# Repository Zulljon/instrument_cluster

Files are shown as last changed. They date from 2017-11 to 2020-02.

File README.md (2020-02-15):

View this project on [CADLAB.io](https://cadlab.io/project/2495). 

# ECU emulator v3.1a
PCB part of project (source codes unavailable!)

## Scheme
in development...
in development...
in development...
in development...

## PCB
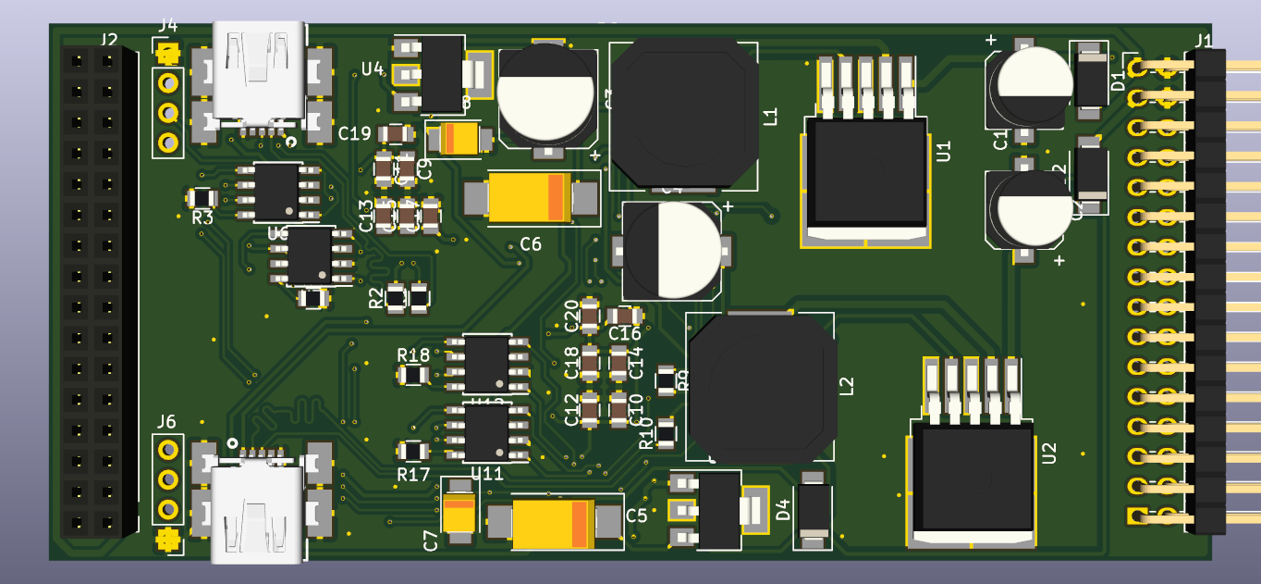
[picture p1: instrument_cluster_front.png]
front side in development...

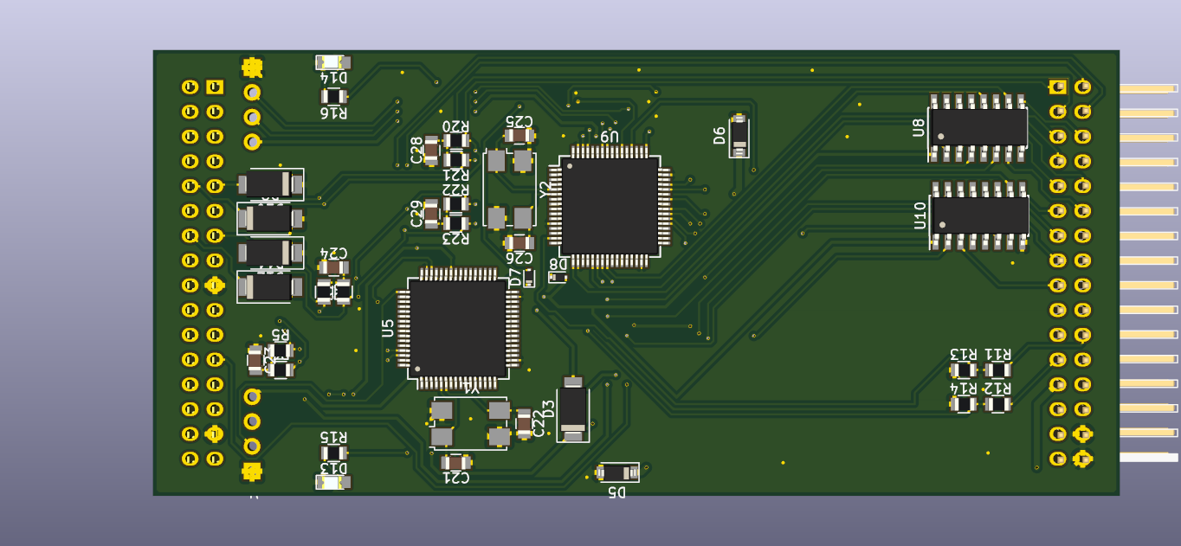
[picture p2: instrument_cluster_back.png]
back side in development...

### With FreeCAD PCB mod
in development...
### With FreeCAD KiCAD StepUp mod
in development...

## Tools
- KiCAD v4.0.7
- FreeCAD v0.15

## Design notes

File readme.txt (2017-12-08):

Name of each file consists from name of project and it`s purpose, for example:
	Rover_Commander_v3.1a-B.Cu.gbr
		Rover_Commander_v3.1a - project name
		-B.Cu.gbr - нижний слой меди

соответственно:
	
	*-B.Cu.gbr  	-	back copper layer
	*-B.Fab.gbr 	-	footprint assemly on board`s back 
	*-B.Mask.gbr	-	solder mask on board`s back
	*-B.Paste.gbr	-	solder paste on board`s back
	*-B.SilkS.gbr	-	silkscreen on board`s back
	*-B.CrtYd.gbr	-	footprints courtyards on board`s back
	*-B.Adhes.gbr	-	adhesive on board`s back

	*-F.Cu.gbr  	-	front copper layer
	*-F.Fab.gbr 	-	footprint assemly on board`s front
	*-F.Mask.gbr	-	solder mask on board`s front
	*-F.Paste.gbr	-	solder paste on board`s front
	*-F.SilkS.gbr	-	silkscreen on board`s front
	*-F.CrtYd.gbr	-	footprints courtyards on board`s front
	*-F.Adhes.gbr	-	adhesive on board`s front

	*-Edge.Cuts.gbr	-	board`s perimeter definition
	*.drl			-	excellon drill file
	*-drl_map.gbr	-	map drill file

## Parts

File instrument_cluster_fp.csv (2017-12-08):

Source: | z:/KiCAD/instrument_cluster/instrument_cluster.sch
Date: | 08.12.2017 12:24:34
Tool: | Eeschema 4.0.7
Generator: | C:/Program Files/KiCad/bin/scripting/plugins/bom_csv_grouped_by_value_with_fp.py
Component Count: | 86
Ref | Qnty | Value | Cmp name | Footprint | Description | Vendor
C1, C2, | 2 | 100uF x 30V | CP | Capacitors_SMD:CP_Elec_6.3x7.7 | Polarised capacitor
C3, C4, | 2 | 330uF x 10V | CP | Capacitors_SMD:CP_Elec_8x10 | Polarised capacitor
C5, C6, | 2 | 100uF x 10V | CP | Capacitors_Tantalum_SMD:CP_Tantalum_Case-D_EIA-7343-31_Hand | Polarised capacitor
C7, C8, | 2 | 10uF x 10V | CP | Capacitors_Tantalum_SMD:CP_Tantalum_Case-B_EIA-3528-21_Wave | Polarised capacitor
C9, C11, C13, C15, C17, C10, C12, C14, C16, C18, | 10 | 100nF | C | Capacitors_SMD:C_0805 | Unpolarized capacitor
C19, C20, | 2 | 4.7uF | C | Capacitors_SMD:C_0805 | Unpolarized capacitor
C22, C21, C26, C25, | 4 | 16pF | C | Capacitors_SMD:C_0805 | Unpolarized capacitor
C23, C24, C28, C29, | 4 | 10pF | C | Capacitors_SMD:C_0805 | Unpolarized capacitor
D1, D3, D4, D2, | 4 | SS22A-SS210A-galaxy | D_Schottky | Diodes_SMD:D_SMA | Schottky diode
D5, D6, | 2 | 1N5819 | D_Schottky | Diodes_SMD:D_SOD-123 | Schottky diode
D7, D8, | 2 | PMLL4148L.115 | D | Diodes_SMD:D_SC-80 | Diode
D10, D9, D11, D12, | 4 | SMAJ33CA-TR | D_TVS | Diodes_SMD:D_SMA | Bidirectional transient-voltage-suppression (TVS) diode
D13, D14, | 2 | LED | LED | LEDs:LED_0805 | LED generic
J1, | 1 | Conn_02x16_Top_Bottom | Conn_02x16_Top_Bottom | zulljon:Pin_Header_Angled_2x16_Pitch2.54mm | Generic connector, double row, 02x16, top/bottom pin numbering scheme (row 1: 1...pins_per_row, row2: pins_per_row+1 ... num_pins)
J2, | 1 | Conn_02x16_Top_Bottom | Conn_02x16_Top_Bottom | zulljon:Socket_Strip_Straight_2x16_Pitch2.54mm | Generic connector, double row, 02x16, top/bottom pin numbering scheme (row 1: 1...pins_per_row, row2: pins_per_row+1 ... num_pins)
J3, | 1 | USB mini-B SMD | 54819-0572 | zpkl:USB_mini_B | Surface mount onthego connector,1A 30V Molex On-The-Go Series Right Angle SMT Version 2.0 Type B Mini USB Connector Receptacle, 30 V, 1A
J4, J6, | 2 | NOT_FITTED_SWD_Conn_01x04_Male | Conn_01x04_Male | Pin_Headers:Pin_Header_Straight_1x04_Pitch2.54mm | Generic connector, single row, 01x04
J5, | 1 | 54819-0572 | 54819-0572 | zpkl:USB_mini_B | Surface mount onthego connector,1A 30V Molex On-The-Go Series Right Angle SMT Version 2.0 Type B Mini USB Connector Receptacle, 30 V, 1A
L1, L2, | 2 | 330uH | L | Inductors_SMD:L_12x12mm_h8mm | Inductor
R2, R1, R10, R9, | 4 | 22 | R | Resistors_SMD:R_0805 | Resistor
R3, R4, R17, R18, R16, | 5 | 10k | R | Resistors_SMD:R_0805 | Resistor
R6, R5, R8, R7, R21, R20, R23, R22, | 8 | 60 | R | Resistors_SMD:R_0805 | Resistor
R11, R12, | 2 | 9k | R | Resistors_SMD:R_0805 | Resistor
R13, R14, | 2 | 2.2k | R | Resistors_SMD:R_0805 | Resistor
R15, | 1 | 1k | R | Resistors_SMD:R_0805 | Resistor
U1, U2, | 2 | LM2575S-5.0_NOPB | LM2575S-5.0_NOPB | TO_SOT_Packages_SMD:TO-263-5_TabPin6 | SIMPLE SWITCHER 4.5V to 40V, 1A Low Component Count Step-Down Regulator
U3, U4, | 2 | LD1117S33TR_SOT223 | LD1117S33TR_SOT223 | TO_SOT_Packages_SMD:SOT-223-3_TabPin2 | 1A Low Dropout regulator, positive, 1.5V fixed output, SOT-223
U5, U9, | 2 | STM32F105RBTx | STM32F105RBTx-RESCUE-instrument_cluster | Housings_QFP:LQFP-64_10x10mm_Pitch0.5mm
U6, U7, U11, U12, | 4 | TJA1040T | TJA1040T | Housings_SOIC:SOIC-8_3.9x4.9mm_Pitch1.27mm | TJA1040T, High-Speed CAN Transceiver, standby mode, split pin, SOIC-8
U10, U8, | 2 | 74HC4050D | 74HC4050D | Housings_SOIC:SOIC-16_3.9x9.9mm_Pitch1.27mm | 74HC4050D, 6-Bit Buffer, Converter, HC, Non-Inverting 2 to 6V 16-Pin SOIC
Y1, Y2, | 2 | Crystal KX-13 25MHz | Crystal_GND24 | Crystals:Crystal_SMD_7050-4pin_7.0x5.0mm | Four pin crystal (GND on pins 2 and 4), e.g. in SMD package

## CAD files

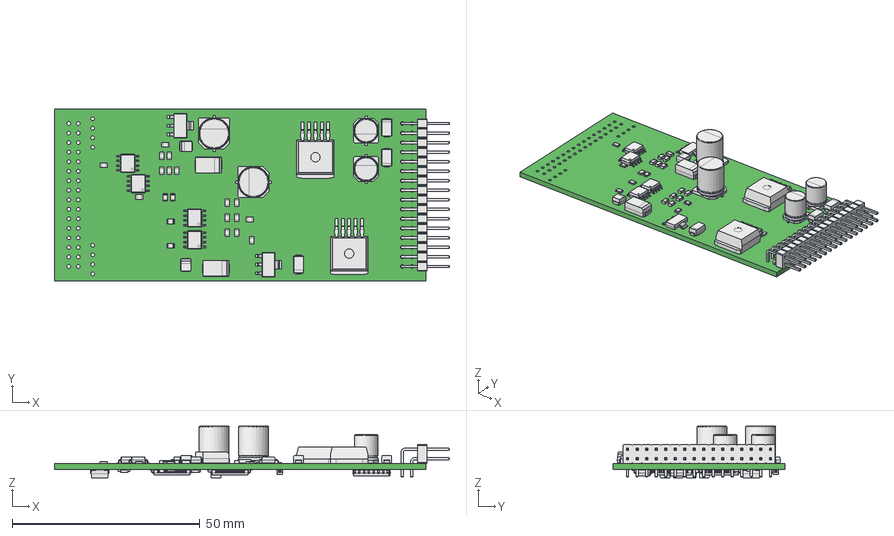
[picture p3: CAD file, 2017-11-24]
instrument_cluster.FCStd
105.3 x 45.7 x 13.8 mm
Pcb
CP_Elec_6.3x7.7_
CP_Elec_6.3x7.7_001
CP_Elec_8x1.0_
CP_Elec_8x1.0_001
CP_Tantalum_Case-D_EIA-7343-31_
CP_Tantalum_Case-D_EIA-7343-31_001
CP_Tantalum_Case-B_EIA-3528-21_
CP_Tantalum_Case-B_EIA-3528-21_001
C_0805_
C_0805_001
C_0805_002
C_0805_003
C_0805_004
C_0805_005
C_0805_006
C_0805_007
C_0805_008
C_0805_009
C_0805_010
C_0805_011
C_0805_012
C_0805_013
C_0805_014
C_0805_015
C_0805_016
C_0805_017
C_0805_018
C_0805_019
D_SMA_
D_SMA_001
D_SMA_002
D_SMA_003
D_SOD_123_
D_SOD_123_001
D_SC_80_
D_SC_80_001
R_0805_
R_0805_001
R_0805_002
R_0805_003
R_0805_004
R_0805_005
R_0805_006
R_0805_007
R_0805_008
R_0805_009
R_0805_010
R_0805_011
R_0805_012
R_0805_013
R_0805_014
R_0805_015
R_0805_016
R_0805_017
SOT_223_
SOT_223_001
SOIC-8_3.9x4.9mm_Pitch1.27mm_
SOIC-8_3.9x4.9mm_Pitch1.27mm_001
SOIC-16_3.9x9.9mm_Pitch1.27mm_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

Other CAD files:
instrument_cluster1.stl

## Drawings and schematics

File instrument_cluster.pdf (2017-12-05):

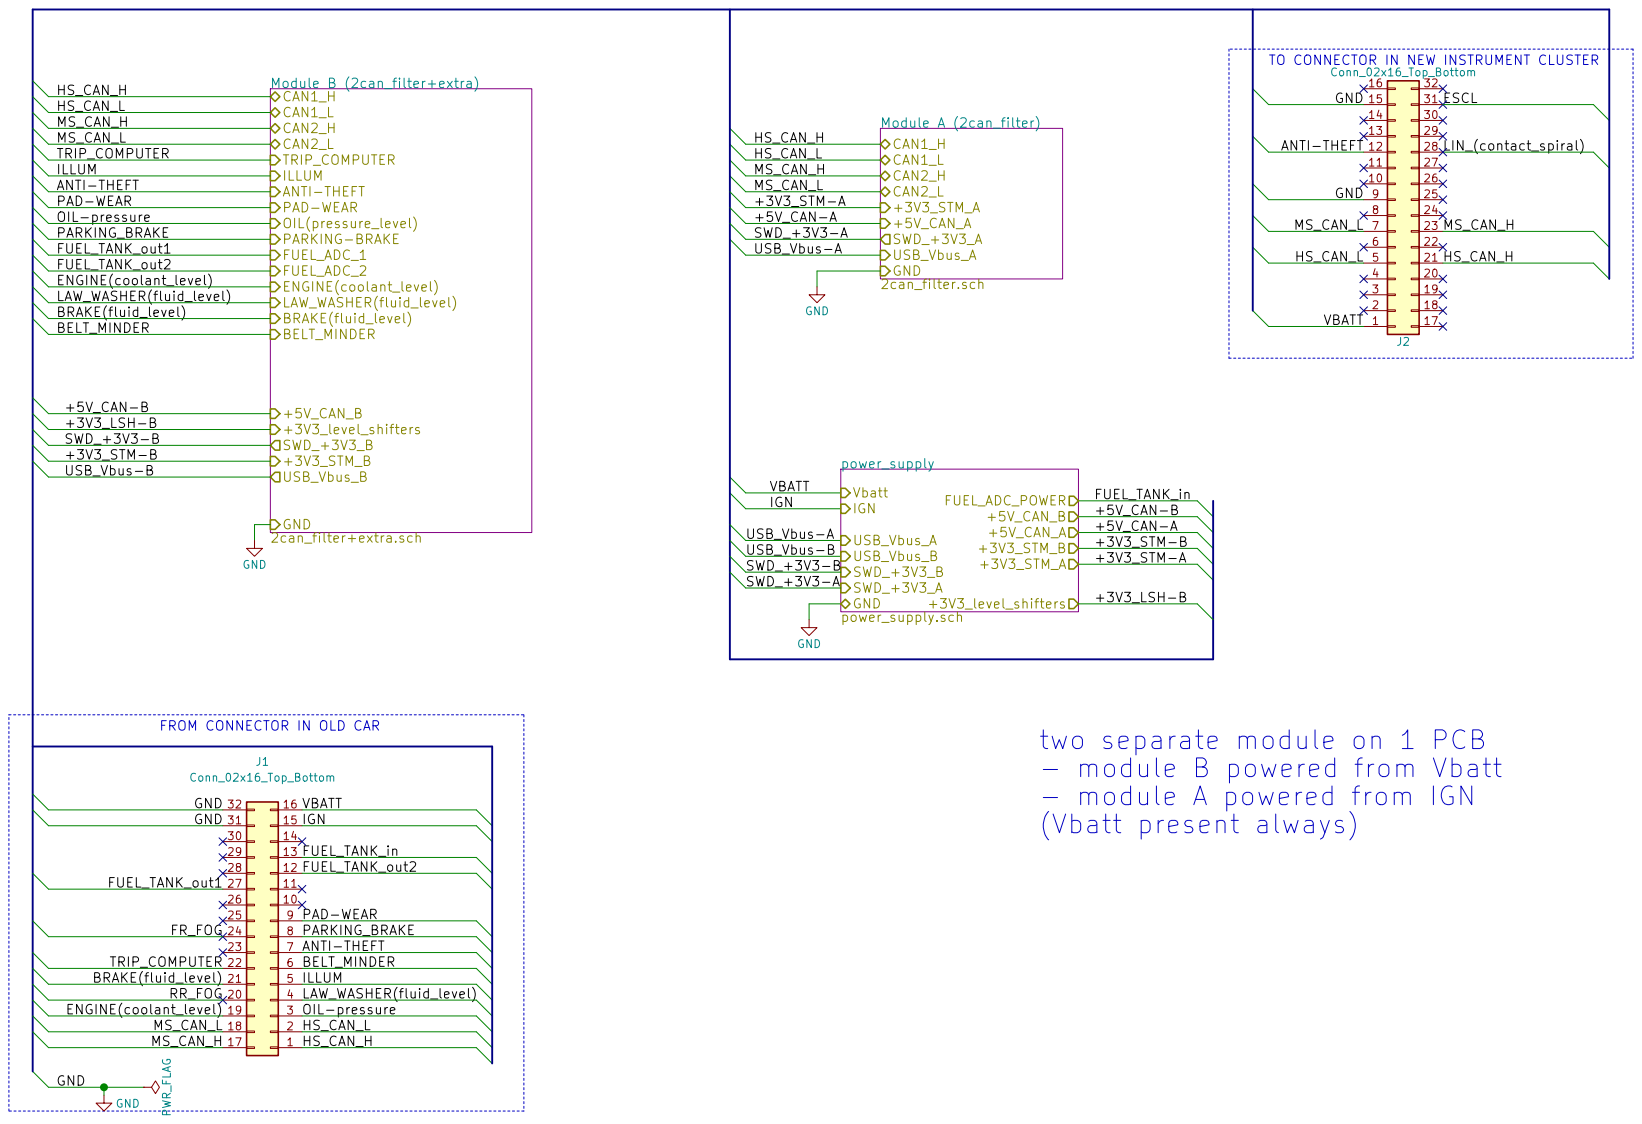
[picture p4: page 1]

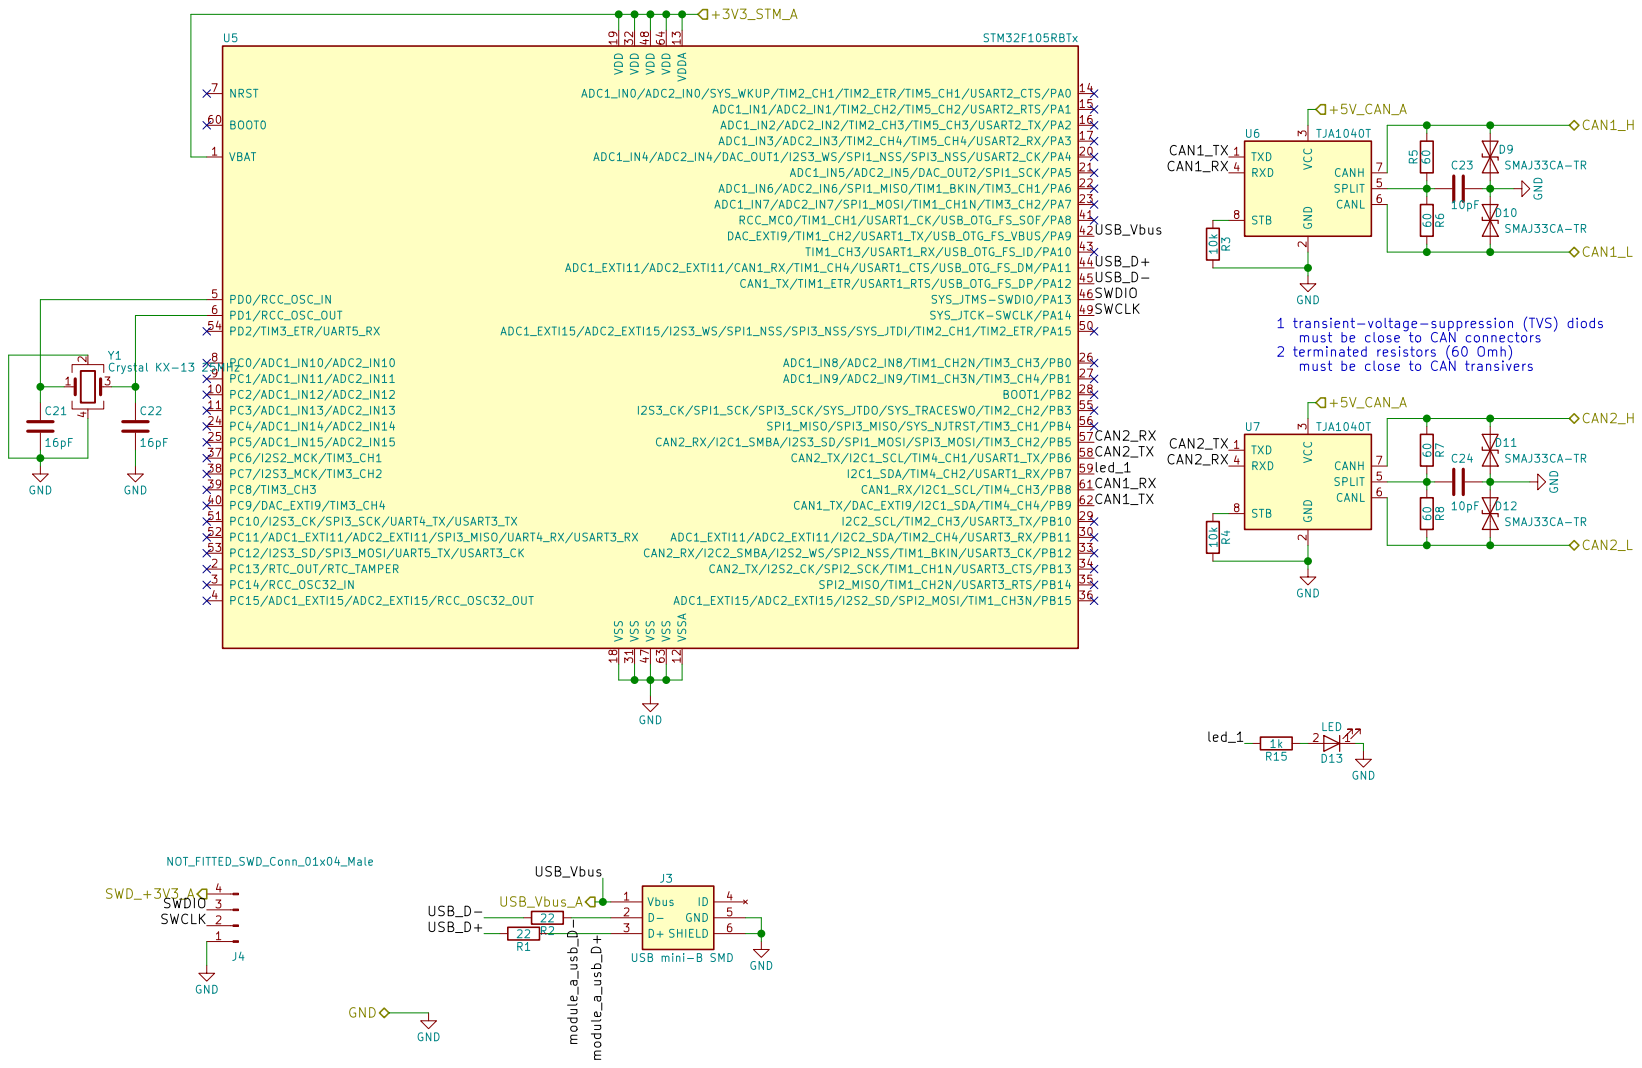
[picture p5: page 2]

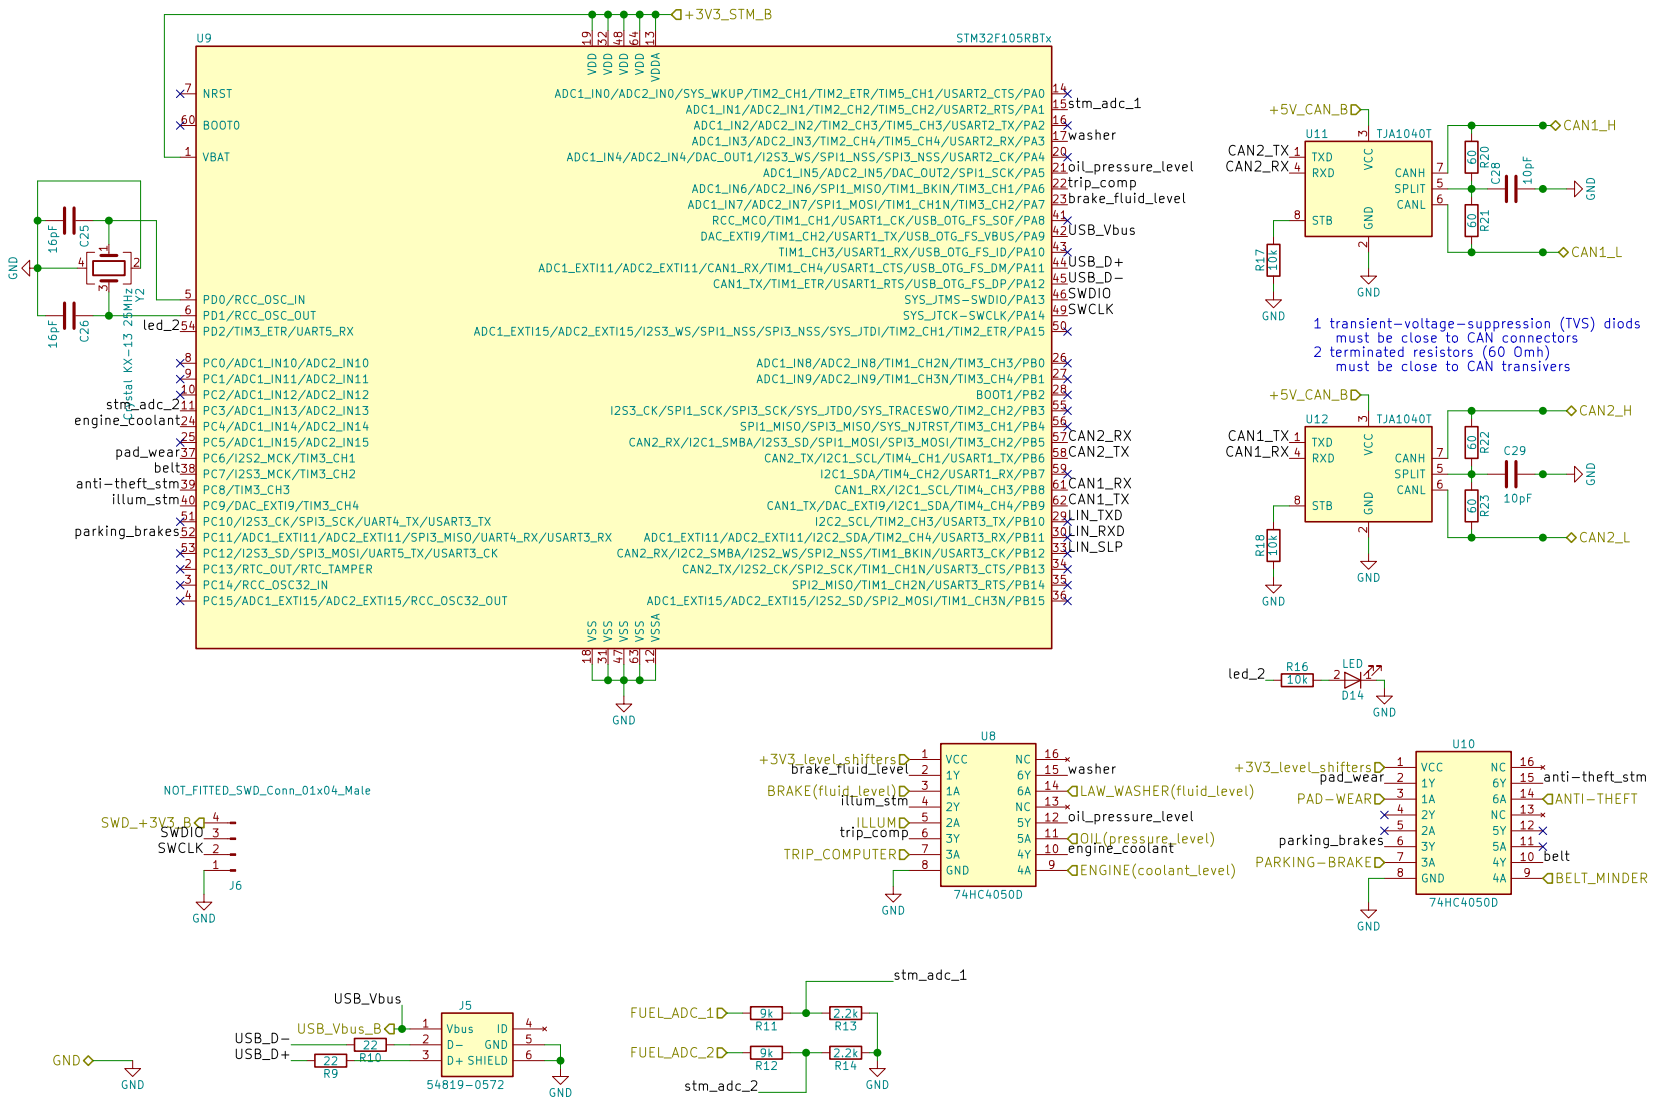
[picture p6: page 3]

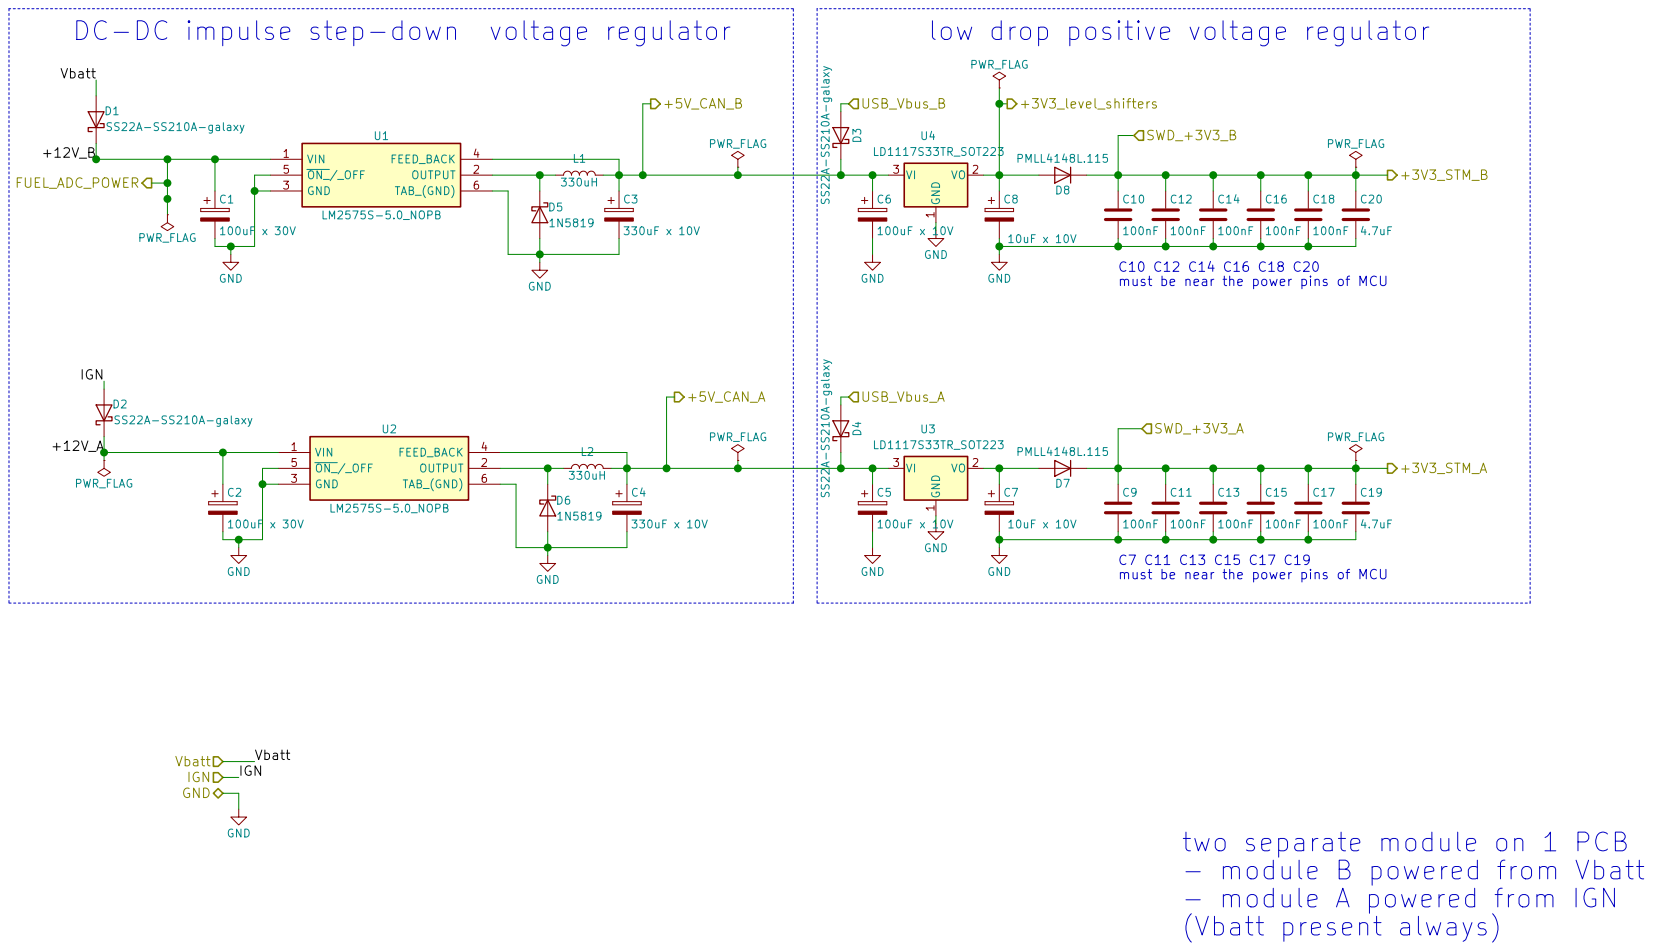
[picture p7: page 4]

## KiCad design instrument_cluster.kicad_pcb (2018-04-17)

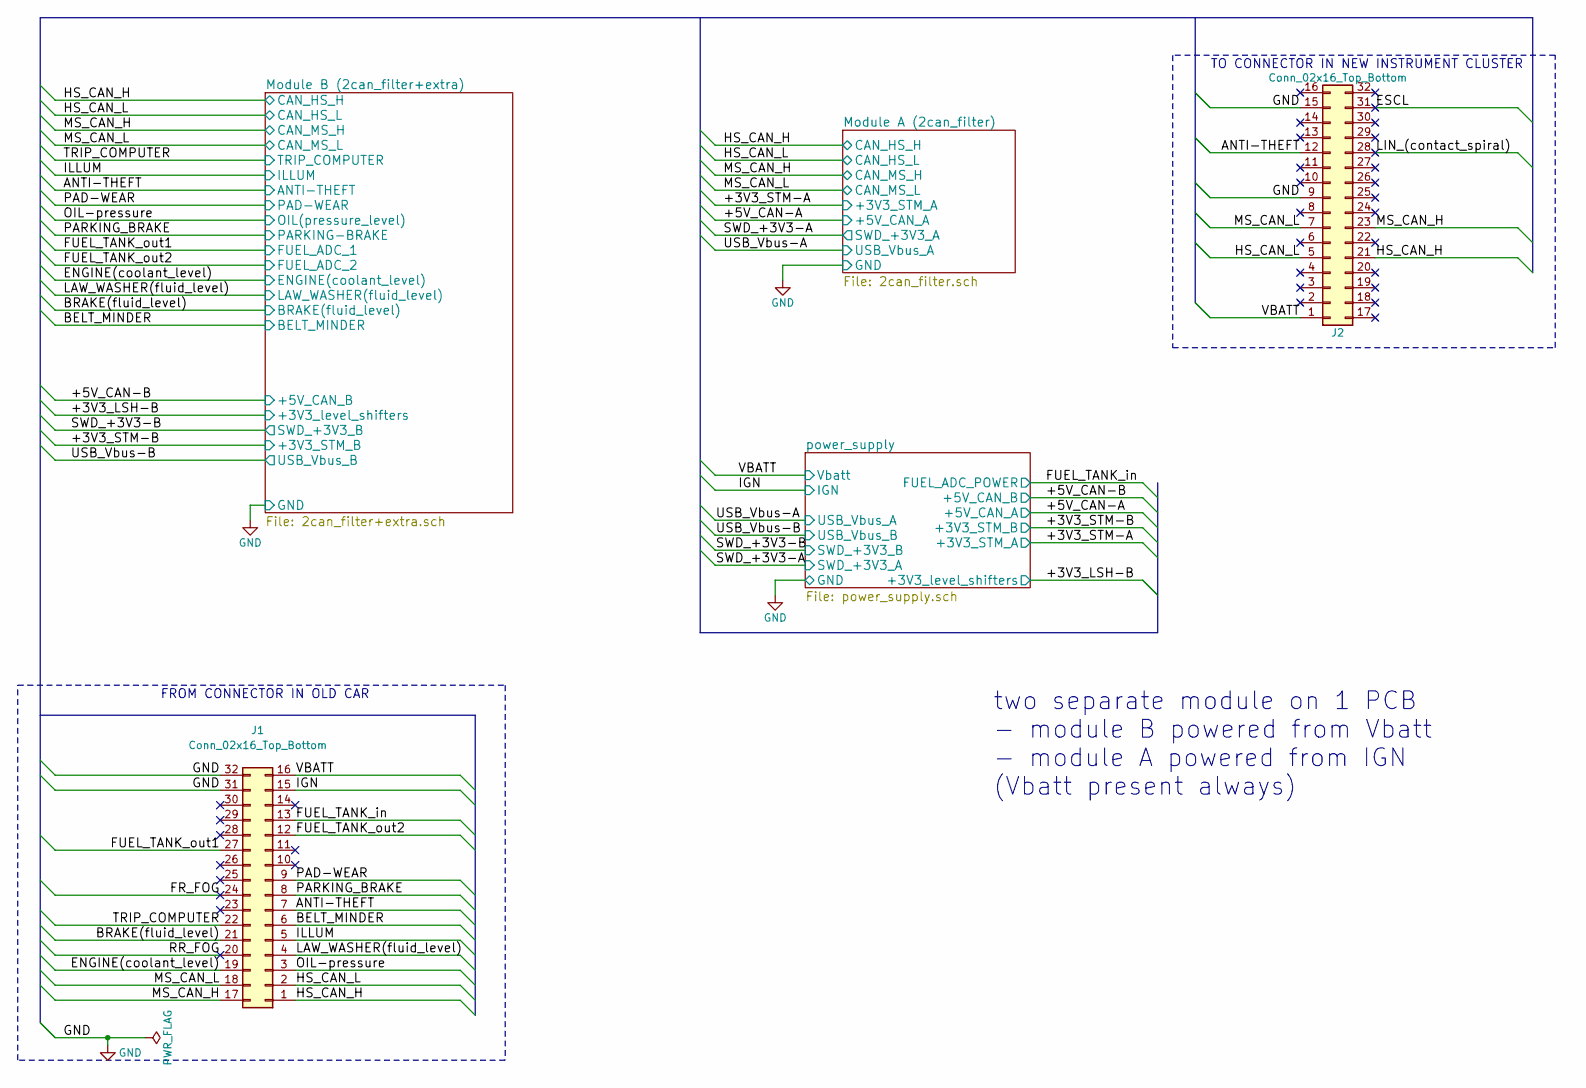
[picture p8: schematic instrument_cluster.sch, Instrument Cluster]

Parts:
J1: Conn_02x16_Top_Bottom; Pin_Header_Angled_2x16_Pitch2.54mm
J2: Conn_02x16_Top_Bottom; Socket_Strip_Straight_2x16_Pitch2.54mm

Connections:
/ANTI-THEFT: J1.7, J2.12; also elsewhere on the board
/BELT_MINDER: J1.6; also elsewhere on the board
/BRAKE(fluid_level): J1.21; also elsewhere on the board
/ENGINE(coolant_level): J1.19; also elsewhere on the board
/ESCL: J2.31
/FR_FOG: J1.24
/FUEL_TANK_in: J1.13; also elsewhere on the board
/FUEL_TANK_out1: J1.27; also elsewhere on the board
/FUEL_TANK_out2: J1.12; also elsewhere on the board
/HS_CAN_H: J1.1, J2.21; also elsewhere on the board
/HS_CAN_L: J1.2, J2.5; also elsewhere on the board
/IGN: J1.15; also elsewhere on the board
/ILLUM: J1.5; also elsewhere on the board
/LAW_WASHER(fluid_level): J1.4; also elsewhere on the board
/LIN_(contact_spiral): J2.28
/MS_CAN_H: J1.17, J2.23; also elsewhere on the board
/MS_CAN_L: J1.18, J2.7; also elsewhere on the board
/OIL-pressure: J1.3; also elsewhere on the board
/PAD-WEAR: J1.9; also elsewhere on the board
/PARKING_BRAKE: J1.8; also elsewhere on the board
/RR_FOG: J1.20
/TRIP_COMPUTER: J1.22; also elsewhere on the board
/VBATT: J1.16, J2.1; also elsewhere on the board
GND: J1.31, J1.32, J2.9, J2.15; also elsewhere on the board

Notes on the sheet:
FROM CONNECTOR IN OLD CAR
TO CONNECTOR IN NEW INSTRUMENT CLUSTER
two separate module on 1 PCB - module B powered from Vbatt - module A powered from IGN (Vbatt present always)

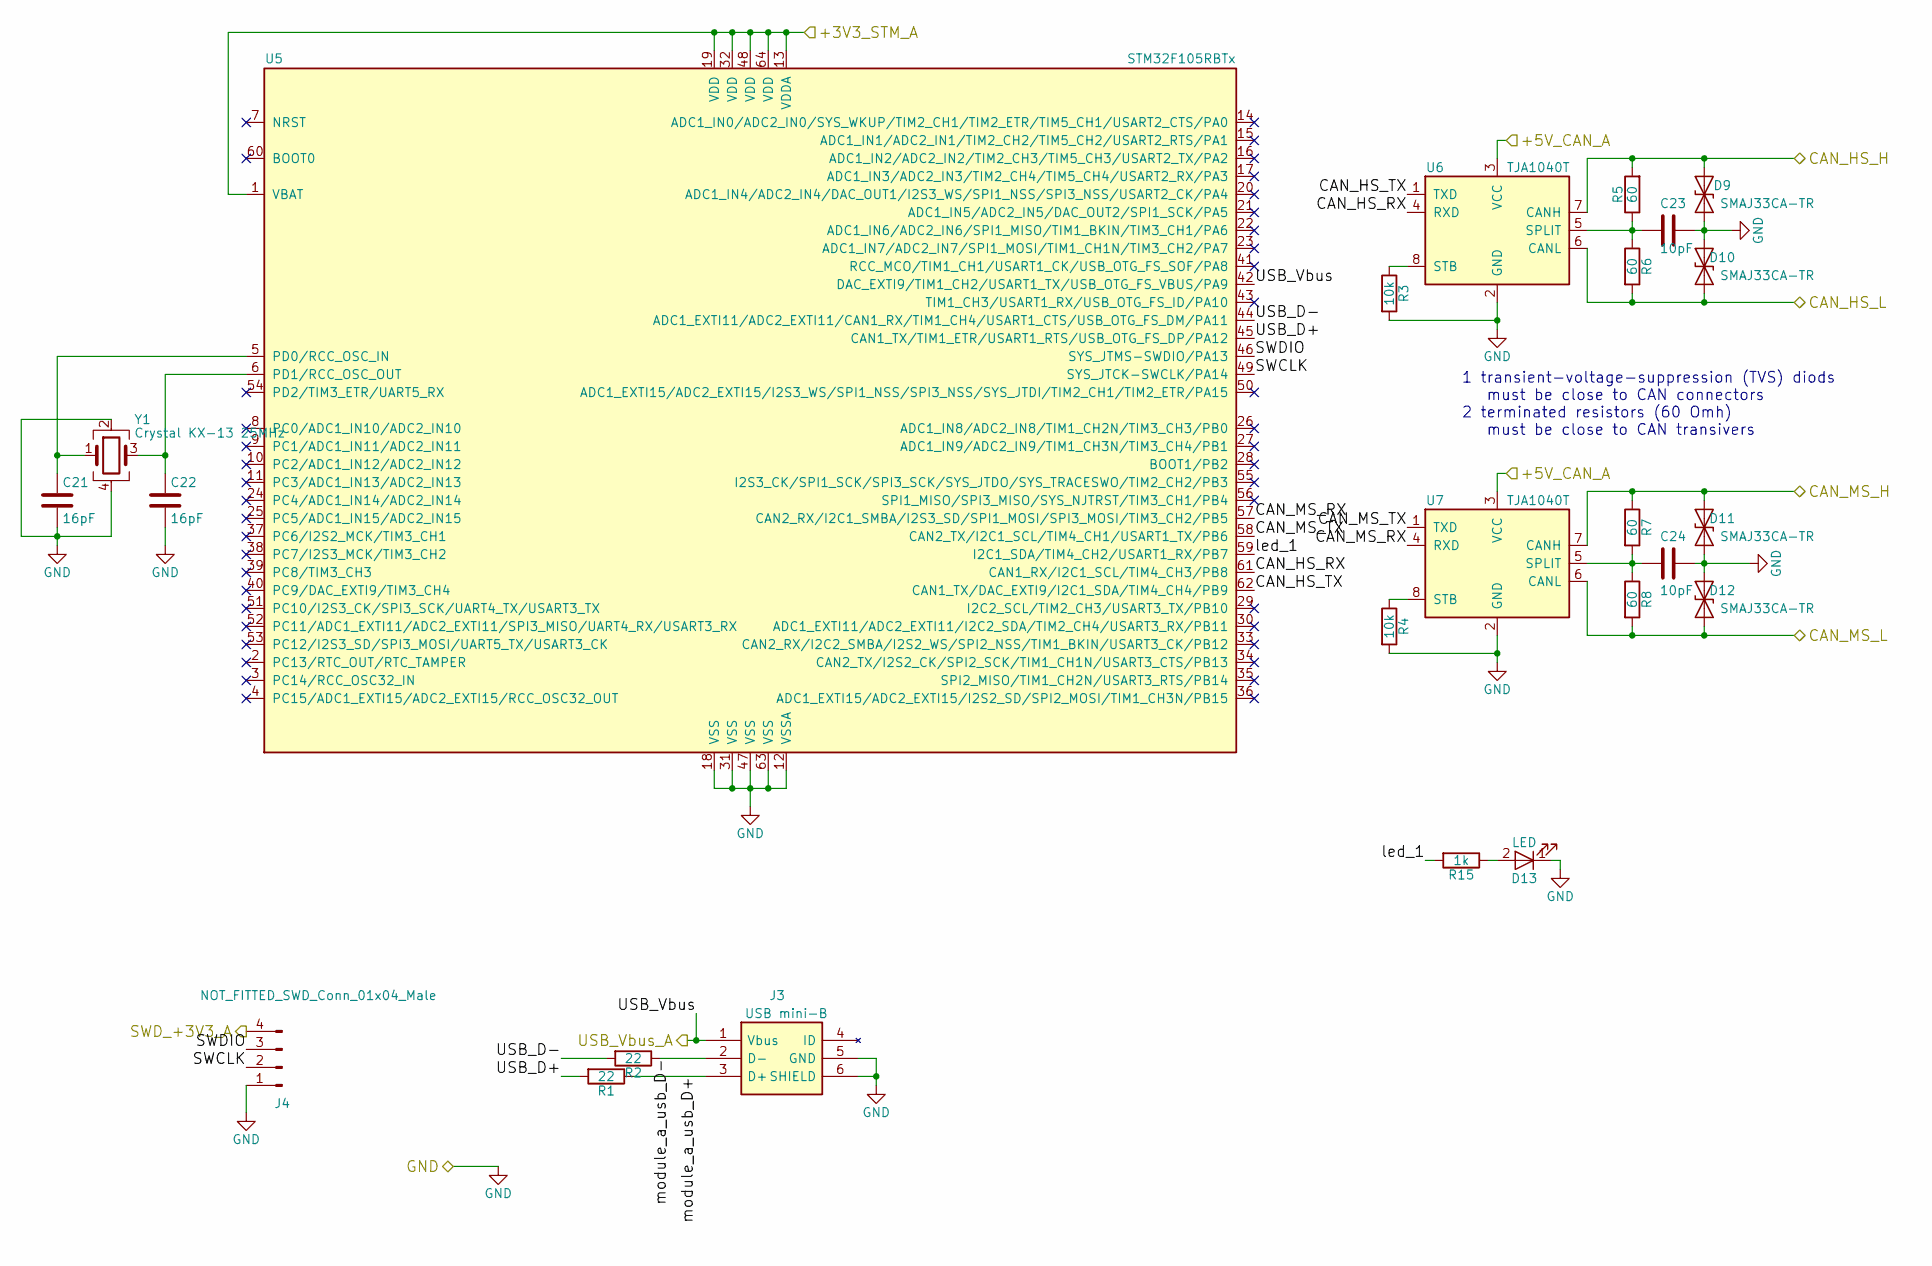
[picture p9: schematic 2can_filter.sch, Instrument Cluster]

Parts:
C21, C22: 16pF; C_0805
C23, C24: 10pF; C_0805
D9, D10, D11, D12: SMAJ33CA-TR; D_SMA
D13: LED; LED_0805
J3: USB mini-B; USB-B-M5-SMD-C; Manufacturer_Part_Number 54819-0572
J4: NOT_FITTED_SWD_Conn_01x04_Male; Pin_Header_Straight_1x04_Pitch2.54mm
R1, R2: 22; R_0805
R3, R4: 10k; R_0805
R5, R6, R7, R8: 60; R_0805
R15: 1k; R_0805
U5: STM32F105RBTx; LQFP-64_10x10mm_Pitch0.5mm
U6, U7: TJA1040T; SOIC-8_3.9x4.9mm_Pitch1.27mm
Y1: Crystal KX-13 25MHz; Crystal_SMD_7050-4pin_7.0x5.0mm

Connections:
/+3V3_STM-A: J4.4, U5.1 (VBAT), U5.13 (VDDA), U5.19 (VDD), U5.32 (VDD), U5.48 (VDD), U5.64 (VDD); also elsewhere on the board
/+5V_CAN-A: U6.3 (VCC), U7.3 (VCC); also elsewhere on the board
/HS_CAN_H: D9.1 (A1), R5.2, U6.7 (CANH); also elsewhere on the board
/HS_CAN_L: D10.2 (A2), R6.2, U6.6 (CANL); also elsewhere on the board
/MS_CAN_H: D11.1 (A1), R7.1, U7.7 (CANH); also elsewhere on the board
/MS_CAN_L: D12.2 (A2), R8.2, U7.6 (CANL); also elsewhere on the board
/Module A (2can_filter)/CAN_HS_RX: U5.61 (CAN1_RX/I2C1_SCL/TIM4_CH3/PB8), U6.4 (RXD)
/Module A (2can_filter)/CAN_HS_TX: U5.62 (CAN1_TX/DAC_EXTI9/I2C1_SDA/TIM4_CH4/PB9), U6.1 (TXD)
/Module A (2can_filter)/CAN_MS_RX: U5.57 (CAN2_RX/I2C1_SMBA/I2S3_SD/SPI1_MOSI/SPI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), U7.4 (RXD)
/Module A (2can_filter)/CAN_MS_TX: U5.58 (CAN2_TX/I2C1_SCL/TIM4_CH1/USART1_TX/PB6), U7.1 (TXD)
/Module A (2can_filter)/SWCLK: J4.2, U5.49 (SYS_JTCK-SWCLK/PA14)
/Module A (2can_filter)/SWDIO: J4.3, U5.46 (SYS_JTMS-SWDIO/PA13)
/Module A (2can_filter)/USB_D+: R1.2, U5.45 (CAN1_TX/TIM1_ETR/USART1_RTS/USB_OTG_FS_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)
/Module A (2can_filter)/USB_D-: R2.2, U5.44 (ADC1_EXTI11/ADC2_EXTI11/CAN1_RX/TIM1_CH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)
/Module A (2can_filter)/led_1: R15.2, U5.59 (I2C1_SDA/TIM4_CH2/USART1_RX/PB7)
/Module A (2can_filter)/module_a_usb_D+: J3.3 (D+), R1.1
/Module A (2can_filter)/module_a_usb_D-: J3.2 (D-), R2.1
/USB_Vbus-A: J3.1 (Vbus), U5.42 (DAC_EXTI9/TIM1_CH2/USART1_TX/USB_OTG_FS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); also elsewhere on the board
GND: C21.2, C22.2, C23.1, C24.1, D9.2 (A2), D10.1 (A1), D11.2 (A2), D12.1 (A1), D13.1 (K), J3.5 (GND), J3.6 (SHIELD), J4.1, R3.2, R4.2, U5.12 (VSSA), U5.18 (VSS), U5.31 (VSS), U5.47 (VSS), U5.63 (VSS), U6.2 (GND), U7.2 (GND), Y1.2, Y1.4; also elsewhere on the board
unnamed: C21.1, U5.5 (PD0/RCC_OSC_IN), Y1.1
unnamed: C22.1, U5.6 (PD1/RCC_OSC_OUT), Y1.3
unnamed: C23.2, R5.1, R6.1, U6.5 (SPLIT)
unnamed: C24.2, R7.2, R8.1, U7.5 (SPLIT)
unnamed: D13.2 (A), R15.1
unnamed: R3.1, U6.8 (STB)
unnamed: R4.1, U7.8 (STB)

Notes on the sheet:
1 transient-voltage-suppression (TVS) diods must be close to CAN connectors 2 terminated resistors (60 Omh) must be close to CAN transivers

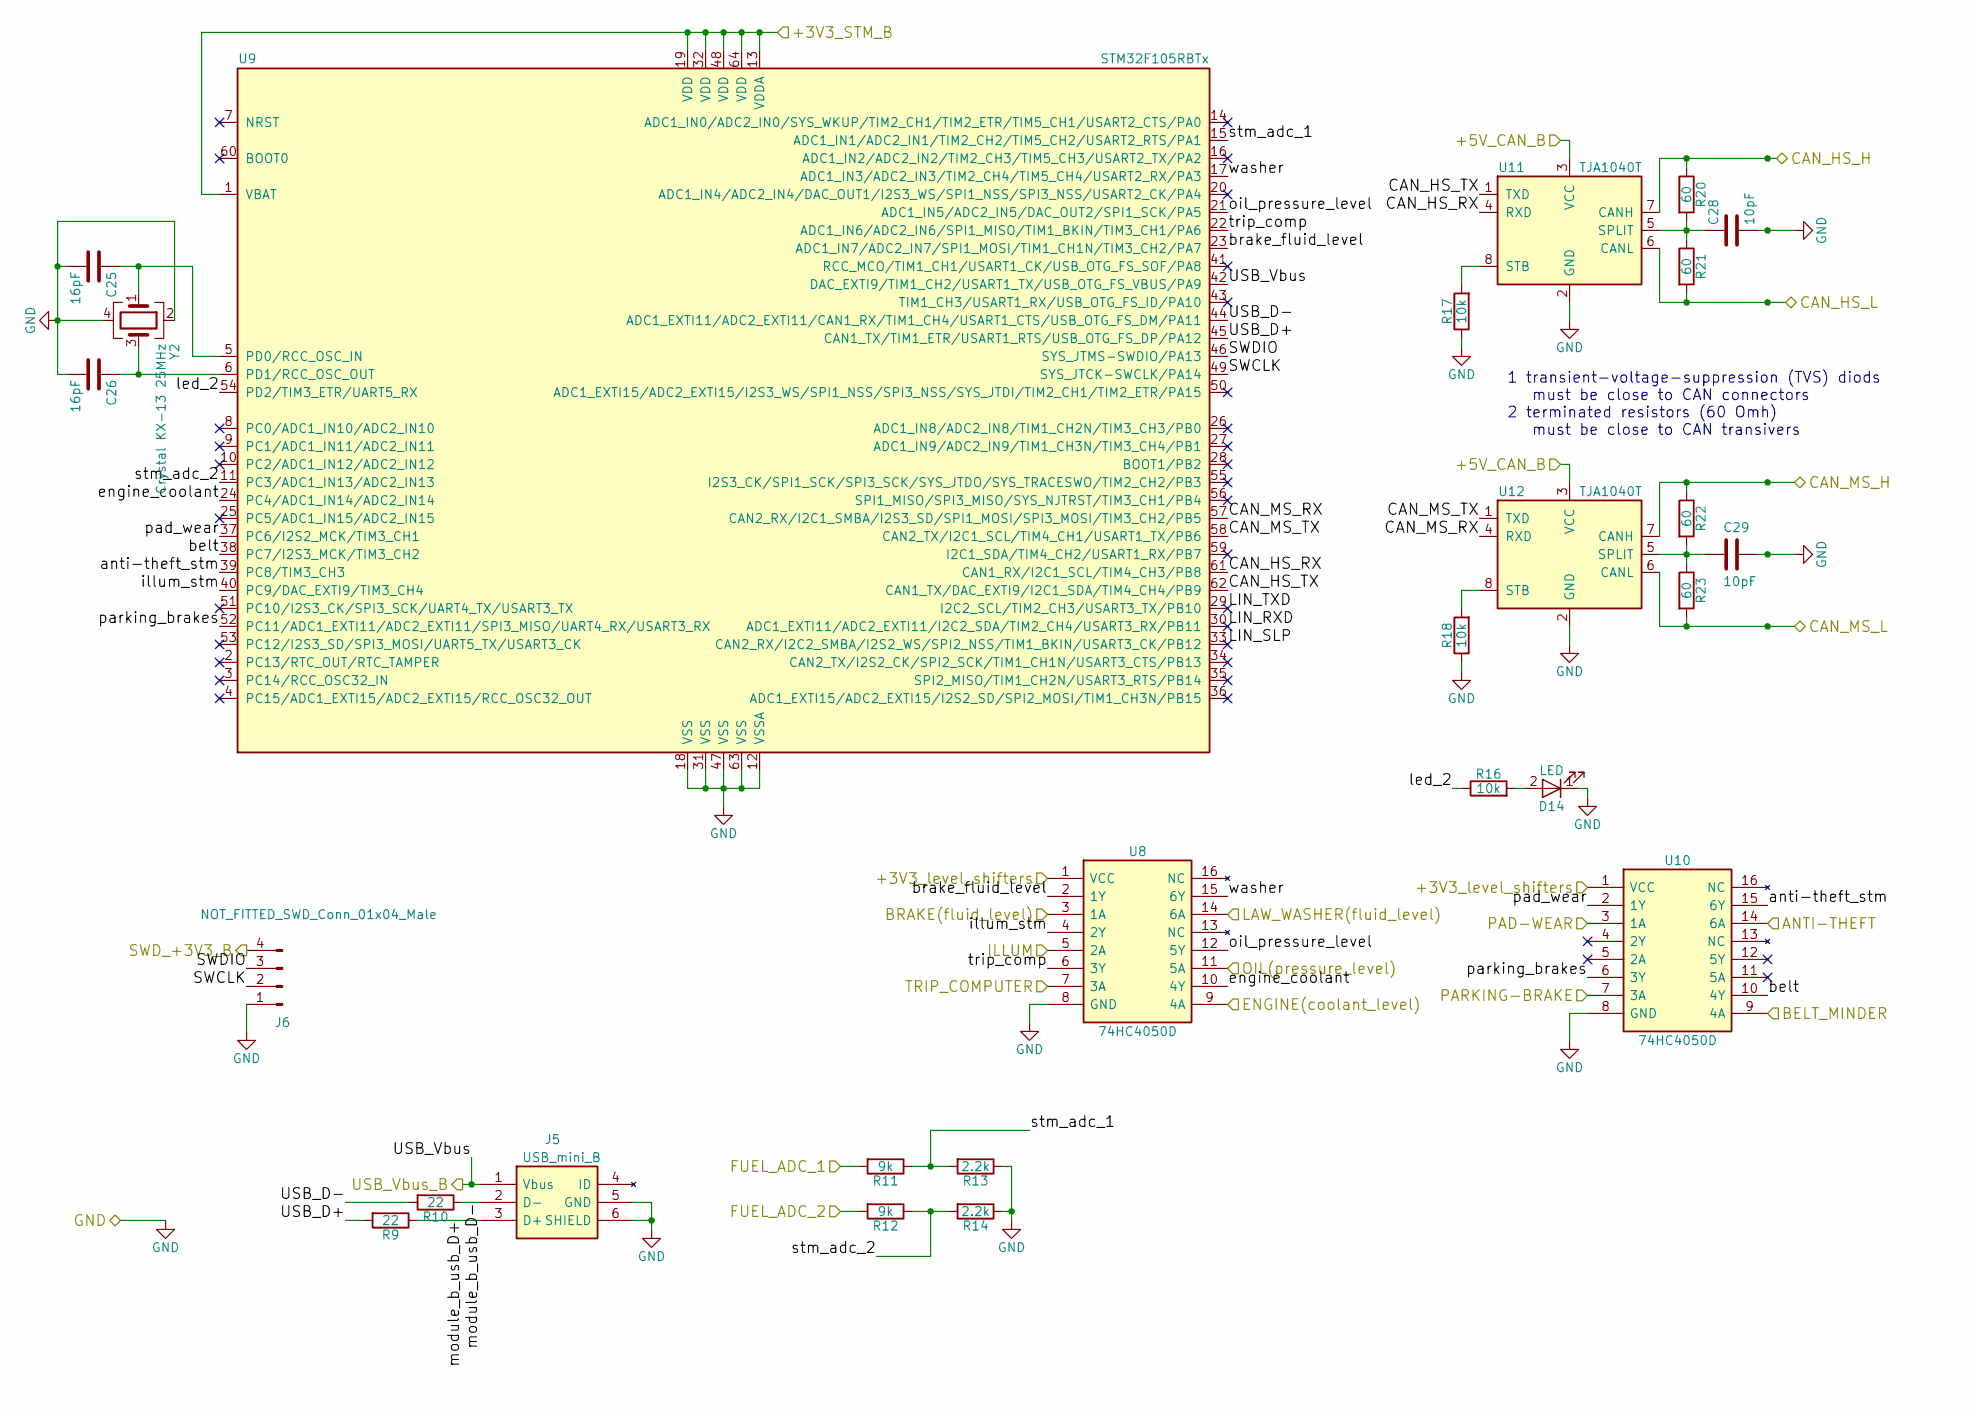
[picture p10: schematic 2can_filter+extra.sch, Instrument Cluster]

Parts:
C25, C26: 16pF; C_0805
C28, C29: 10pF; C_0805
D14: LED; LED_0805
J5: USB_mini_B; USB-B-M5-SMD-C; Manufacturer_Part_Number 54819-0572
J6: NOT_FITTED_SWD_Conn_01x04_Male; Pin_Header_Straight_1x04_Pitch2.54mm
R9, R10: 22; R_0805
R11, R12: 9k; R_0805
R13, R14: 2.2k; R_0805
R16, R17, R18: 10k; R_0805
R20, R21, R22, R23: 60; R_0805
U8, U10: 74HC4050D; SOIC-16_3.9x9.9mm_Pitch1.27mm; Manufacturer_Part_Number 74HC4050D
U9: STM32F105RBTx; LQFP-64_10x10mm_Pitch0.5mm
U11, U12: TJA1040T; SOIC-8_3.9x4.9mm_Pitch1.27mm
Y2: Crystal KX-13 25MHz; Crystal_SMD_7050-4pin_7.0x5.0mm

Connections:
/+3V3_LSH-B: U8.1 (VCC), U10.1 (VCC); also elsewhere on the board
/+3V3_STM-B: J6.4, U9.1 (VBAT), U9.13 (VDDA), U9.19 (VDD), U9.32 (VDD), U9.48 (VDD), U9.64 (VDD); also elsewhere on the board
/+5V_CAN-B: U11.3 (VCC), U12.3 (VCC); also elsewhere on the board
/ANTI-THEFT: U10.14 (6A); also elsewhere on the board
/BELT_MINDER: U10.9 (4A); also elsewhere on the board
/BRAKE(fluid_level): U8.3 (1A); also elsewhere on the board
/ENGINE(coolant_level): U8.9 (4A); also elsewhere on the board
/FUEL_TANK_out1: R11.2; also elsewhere on the board
/FUEL_TANK_out2: R12.2; also elsewhere on the board
/HS_CAN_H: R20.1, U11.7 (CANH); also elsewhere on the board
/HS_CAN_L: R21.2, U11.6 (CANL); also elsewhere on the board
/ILLUM: U8.5 (2A); also elsewhere on the board
/LAW_WASHER(fluid_level): U8.14 (6A); also elsewhere on the board
/MS_CAN_H: R22.1, U12.7 (CANH); also elsewhere on the board
/MS_CAN_L: R23.2, U12.6 (CANL); also elsewhere on the board
/Module B (2can_filter+extra)/CAN_HS_RX: U9.61 (CAN1_RX/I2C1_SCL/TIM4_CH3/PB8), U11.4 (RXD)
/Module B (2can_filter+extra)/CAN_HS_TX: U9.62 (CAN1_TX/DAC_EXTI9/I2C1_SDA/TIM4_CH4/PB9), U11.1 (TXD)
/Module B (2can_filter+extra)/CAN_MS_RX: U9.57 (CAN2_RX/I2C1_SMBA/I2S3_SD/SPI1_MOSI/SPI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), U12.4 (RXD)
/Module B (2can_filter+extra)/CAN_MS_TX: U9.58 (CAN2_TX/I2C1_SCL/TIM4_CH1/USART1_TX/PB6), U12.1 (TXD)
/Module B (2can_filter+extra)/LIN_RXD: U9.30 (ADC1_EXTI11/ADC2_EXTI11/I2C2_SDA/TIM2_C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)
/Module B (2can_filter+extra)/LIN_SLP: U9.33 (CAN2_RX/I2C2_SMBA/I2S2_WS/SPI2_NSS/TIM1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)
/Module B (2can_filter+extra)/LIN_TXD: U9.29 (I2C2_SCL/TIM2_CH3/USART3_TX/PB10)
/Module B (2can_filter+extra)/SWCLK: J6.2, U9.49 (SYS_JTCK-SWCLK/PA14)
/Module B (2can_filter+extra)/SWDIO: J6.3, U9.46 (SYS_JTMS-SWDIO/PA13)
/Module B (2can_filter+extra)/USB_D+: R9.2, U9.45 (CAN1_TX/TIM1_ETR/USART1_RTS/USB_OTG_FS_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)
/Module B (2can_filter+extra)/USB_D-: R10.2, U9.44 (ADC1_EXTI11/ADC2_EXTI11/CAN1_RX/TIM1_CH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)
/Module B (2can_filter+extra)/anti-theft_stm: U9.39 (PC8/TIM3_CH3), U10.15 (6Y)
/Module B (2can_filter+extra)/belt: U9.38 (PC7/I2S3_MCK/TIM3_CH2), U10.10 (4Y)
/Module B (2can_filter+extra)/brake_fluid_level: U8.2 (1Y), U9.23 (ADC1_IN7/ADC2_IN7/SPI1_MOSI/TIM1_CH1N/T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)
/Module B (2can_filter+extra)/engine_coolant: U8.10 (4Y), U9.24 (PC4/ADC1_IN14/ADC2_IN14)
/Module B (2can_filter+extra)/illum_stm: U8.4 (2Y), U9.40 (PC9/DAC_EXTI9/TIM3_CH4)
/Module B (2can_filter+extra)/led_2: R16.1, U9.54 (PD2/TIM3_ETR/UART5_RX)
/Module B (2can_filter+extra)/module_b_usb_D+: J5.3 (D+), R9.1
/Module B (2can_filter+extra)/module_b_usb_D-: J5.2 (D-), R10.1
/Module B (2can_filter+extra)/oil_pressure_level: U8.12 (5Y), U9.21 (ADC1_IN5/ADC2_IN5/DAC_OUT2/SPI1_SCK/PA5)
/Module B (2can_filter+extra)/pad_wear: U9.37 (PC6/I2S2_MCK/TIM3_CH1), U10.2 (1Y)
/Module B (2can_filter+extra)/parking_brakes: U9.52 (PC11/ADC1_EXTI11/ADC2_EXTI11/SPI3_MISO/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), U10.6 (3Y)
/Module B (2can_filter+extra)/stm_adc_1: R11.1, R13.2, U9.15 (ADC1_IN1/ADC2_IN1/TIM2_CH2/TIM5_CH2/USA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)
/Module B (2can_filter+extra)/stm_adc_2: R12.1, R14.2, U9.11 (PC3/ADC1_IN13/ADC2_IN13)
/Module B (2can_filter+extra)/trip_comp: U8.6 (3Y), U9.22 (ADC1_IN6/ADC2_IN6/SPI1_MISO/TIM1_BKIN/T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)
/Module B (2can_filter+extra)/washer: U8.15 (6Y), U9.17 (ADC1_IN3/ADC2_IN3/TIM2_CH4/TIM5_CH4/USA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)
/OIL-pressure: U8.11 (5A); also elsewhere on the board
/PAD-WEAR: U10.3 (1A); also elsewhere on the board
/PARKING_BRAKE: U10.7 (3A); also elsewhere on the board
/TRIP_COMPUTER: U8.7 (3A); also elsewhere on the board
/USB_Vbus-B: J5.1 (Vbus), U9.42 (DAC_EXTI9/TIM1_CH2/USART1_TX/USB_OTG_FS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); also elsewhere on the board
GND: C25.2, C26.2, C28.2, C29.1, D14.1 (K), J5.5 (GND), J5.6 (SHIELD), J6.1, R13.1, R14.1, R17.1, R18.1, U8.8 (GND), U9.12 (VSSA), U9.18 (VSS), U9.31 (VSS), U9.47 (VSS), U9.63 (VSS), U10.8 (GND), U11.2 (GND), U12.2 (GND), Y2.2, Y2.4; also elsewhere on the board
unnamed: C25.1, U9.5 (PD0/RCC_OSC_IN), Y2.1
unnamed: C26.1, U9.6 (PD1/RCC_OSC_OUT), Y2.3
unnamed: C28.1, R20.2, R21.1, U11.5 (SPLIT)
unnamed: C29.2, R22.2, R23.1, U12.5 (SPLIT)
unnamed: D14.2 (A), R16.2
unnamed: R17.2, U11.8 (STB)
unnamed: R18.2, U12.8 (STB)

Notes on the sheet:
1 transient-voltage-suppression (TVS) diods must be close to CAN connectors 2 terminated resistors (60 Omh) must be close to CAN transivers

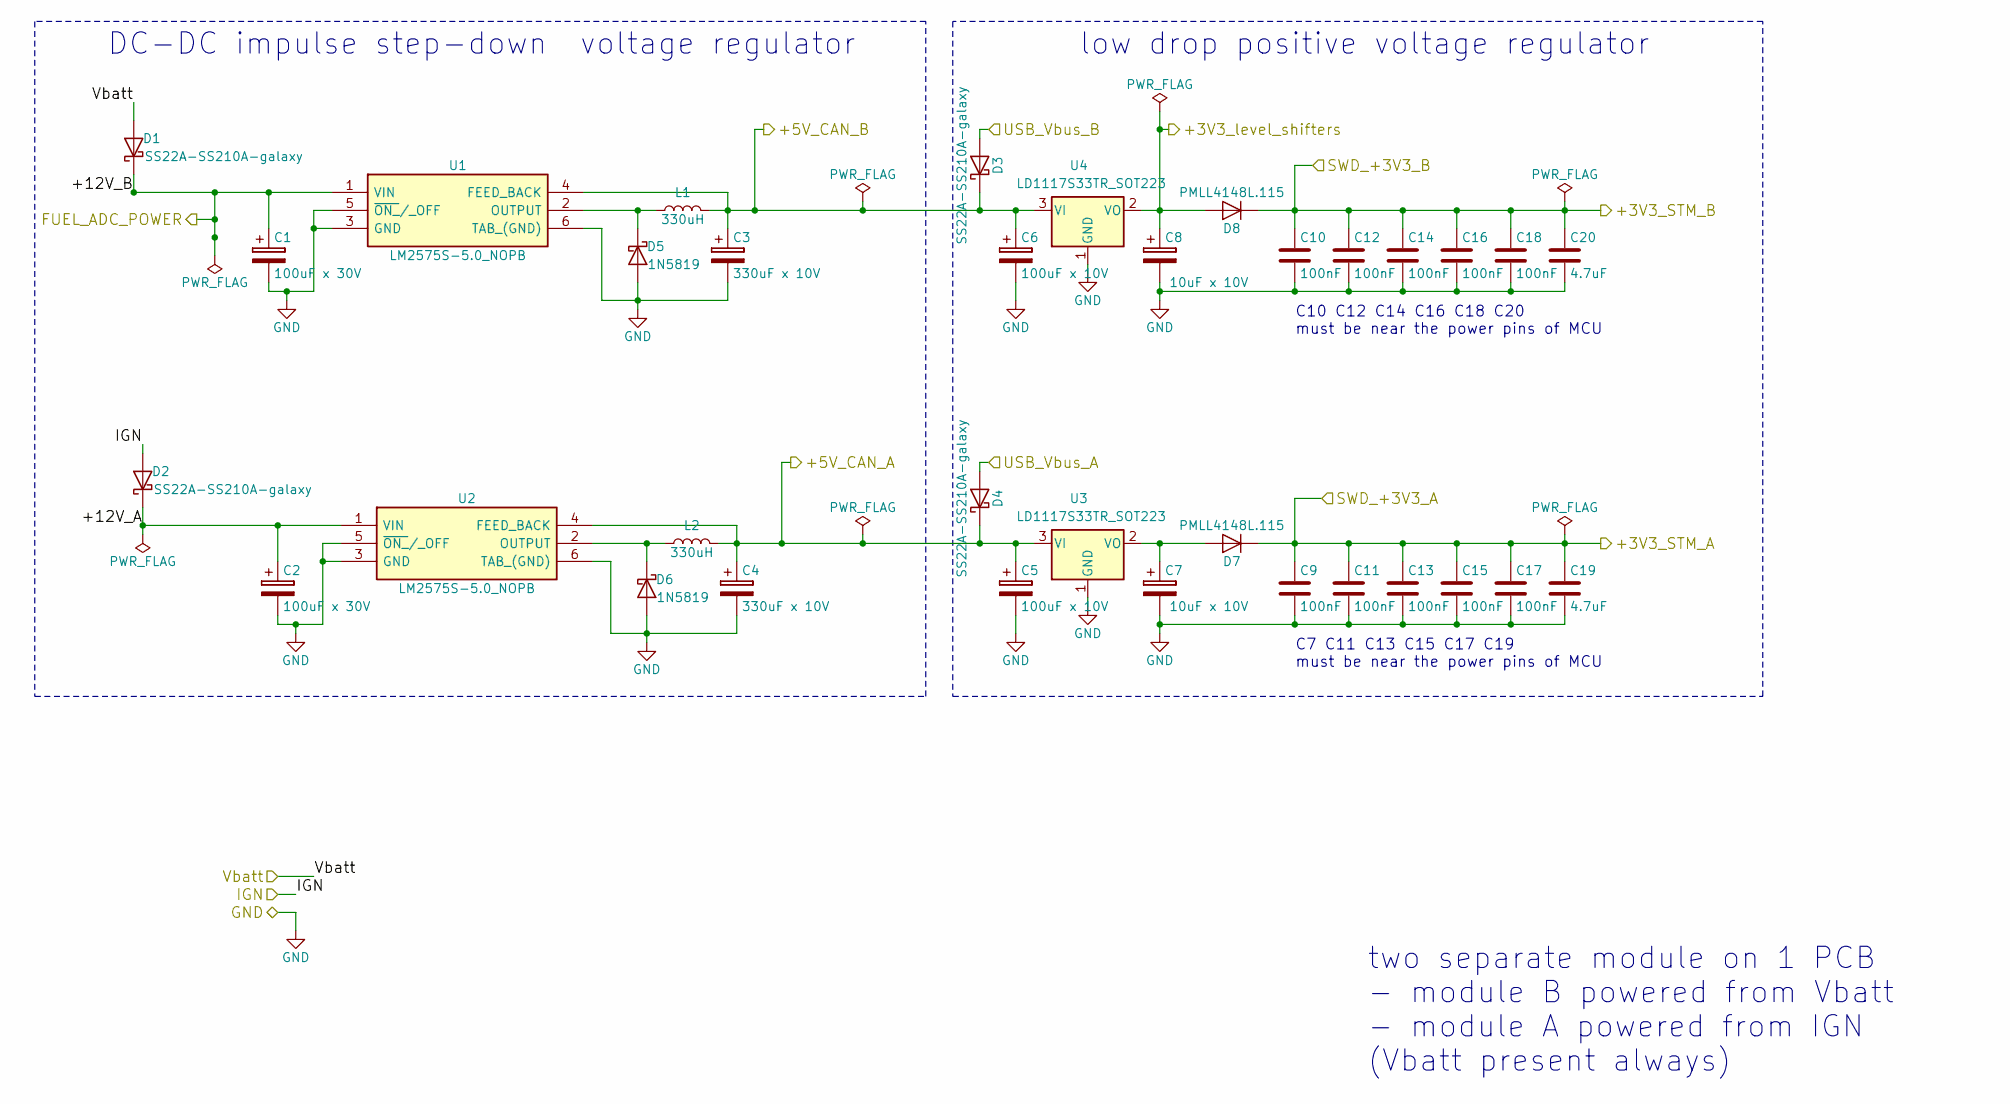
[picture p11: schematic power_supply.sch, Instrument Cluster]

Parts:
C1, C2: 100uF x 30V; CP_Elec_6.3x7.7
C3, C4: 330uF x 10V; CP_Elec_8x10
C5, C6: 100uF x 10V; CP_Tantalum_Case-D_EIA-7343-31_Hand
C7, C8: 10uF x 10V; CP_Tantalum_Case-B_EIA-3528-21_Wave
C9, C10, C11, C12, C13, C14, C15, C16, C17, C18: 100nF; C_0805
C19, C20: 4.7uF; C_0805
D1, D2, D3, D4: SS22A-SS210A-galaxy; D_SMA
D5, D6: 1N5819; D_SOD-123
D7, D8: PMLL4148L.115; D_SC-80
L1, L2: 330uH; L_12x12mm_h8mm
U1, U2: LM2575S-5.0_NOPB; TO-263-5_TabPin6; Manufacturer_Part_Number LM2575S-5.0/NOPB
U3, U4: LD1117S33TR_SOT223; SOT-223-3_TabPin2

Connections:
/+3V3_LSH-B: C8.1, D8.2 (A), U4.2 (VO); also elsewhere on the board
/+3V3_STM-A: C9.1, C11.1, C13.1, C15.1, C17.1, C19.1, D7.1 (K); also elsewhere on the board
/+3V3_STM-B: C10.1, C12.1, C14.1, C16.1, C18.1, C20.1, D8.1 (K); also elsewhere on the board
/+5V_CAN-A: C4.1, C5.1, D4.1 (K), L2.2, U2.4 (FEED_BACK), U3.3 (VI); also elsewhere on the board
/+5V_CAN-B: C3.1, C6.1, D3.1 (K), L1.2, U1.4 (FEED_BACK), U4.3 (VI); also elsewhere on the board
/FUEL_TANK_in: C1.1, D1.1 (K), U1.1 (VIN); also elsewhere on the board
/IGN: D2.2 (A); also elsewhere on the board
/USB_Vbus-A: D4.2 (A); also elsewhere on the board
/USB_Vbus-B: D3.2 (A); also elsewhere on the board
/VBATT: D1.2 (A); also elsewhere on the board
/power_supply/+12V_A: C2.1, D2.1 (K), U2.1 (VIN)
GND: C1.2, C2.2, C3.2, C4.2, C5.2, C6.2, C7.2, C8.2, C9.2, C10.2, C11.2, C12.2, C13.2, C14.2, C15.2, C16.2, C17.2, C18.2, C19.2, C20.2, D5.2 (A), D6.2 (A), U1.3 (GND), U1.5 (~ON_~/_OFF), U1.6 (TAB_(GND)), U2.3 (GND), U2.5 (~ON_~/_OFF), U2.6 (TAB_(GND)), U3.1 (GND), U4.1 (GND); also elsewhere on the board
unnamed: C7.1, D7.2 (A), U3.2 (VO)
unnamed: D5.1 (K), L1.1, U1.2 (OUTPUT)
unnamed: D6.1 (K), L2.1, U2.2 (OUTPUT)

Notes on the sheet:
DC-DC impulse step-down voltage regulator
low drop positive voltage regulator
two separate module on 1 PCB - module B powered from Vbatt - module A powered from IGN (Vbatt present always)
C7 C11 C13 C15 C17 C19 must be near the power pins of MCU
C10 C12 C14 C16 C18 C20 must be near the power pins of MCU

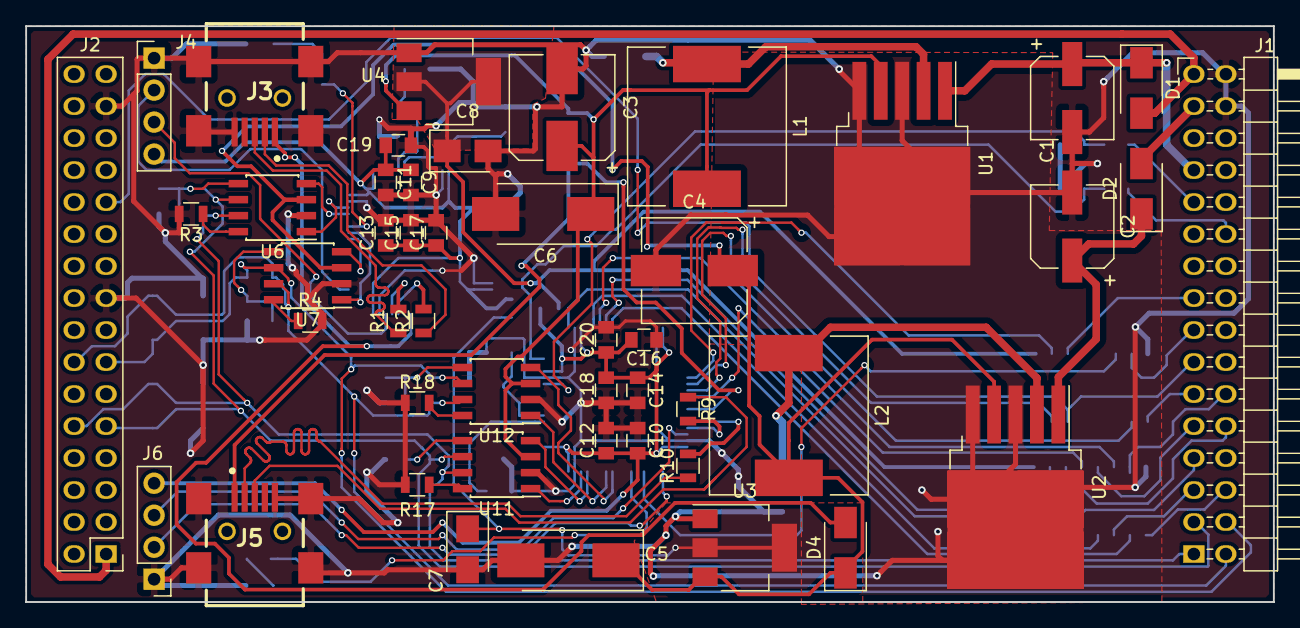
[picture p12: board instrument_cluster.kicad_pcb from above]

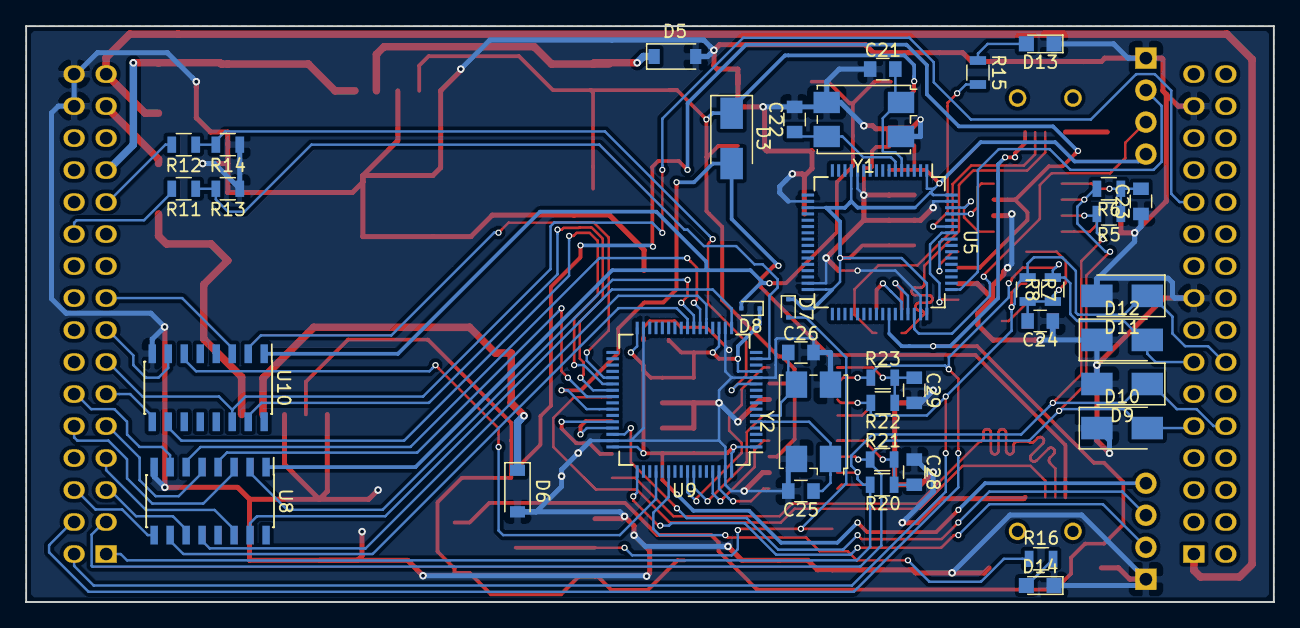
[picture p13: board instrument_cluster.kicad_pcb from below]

Board: 2 copper layers, 99.1 x 45.7 mm, 86 parts (39 on the bottom side), 79 nets.

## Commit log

2017-11-11 remove BOM from gitignore
2017-11-11 add git readme
    [2can_filter+extra.sch, 2can_filter.sch, instrument_cluster.sch]
2017-11-15 finish scheme & change libs path
    [2can_filter+extra.sch, 2can_filter.sch, instrument_cluster.sch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]
2017-11-15 specify footpints to resistors and capasitors
    [2can_filter+extra.sch, 2can_filter.sch, instrument_cluster.sch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]
2017-11-15 switch to my labrary https://github.com/Zulljon/zpkl
2017-11-16 add missed footprints, add additional capasitors on 3.3V line, fix banch of ERC errors
    [2can_filter+extra.sch, 2can_filter.sch, instrument_cluster.sch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]
2017-11-16 add footprints to SWD connectors
    [2can_filter+extra.sch, 2can_filter.sch]
2017-11-16 change usb fp
    [2can_filter+extra.sch, 2can_filter.sch]
2017-11-16 create PCB and import fp from netlist
    [instrument_cluster.kicad_pcb]
2017-11-16 rescue the stm32 mcu_s, add pcb list info
    [2can_filter+extra.sch, 2can_filter.sch, instrument_cluster.kicad_pcb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]
2017-11-16 fix D3 D4 diods connections
    [power_supply.sch]
2017-11-16 pcb part replace
    [instrument_cluster.kicad_pcb]
2017-11-17 fix margins, circuit to edge more >=0.3 mm
    [instrument_cluster.kicad_pcb]
2017-11-17 setup design rule
    [instrument_cluster.kicad_pcb]
2017-11-17 setup design rule2
    [instrument_cluster.kicad_pcb]
2017-11-17 power converters placement complete
    [instrument_cluster.kicad_pcb]
2017-11-17 fix labels in fuel_adc
    [2can_filter+extra.sch]
2017-11-17 change connectivity of level-shifters(on sheme and pcb)
    [2can_filter+extra.sch, instrument_cluster.kicad_pcb]
2017-11-17 fill both side with GND, add heat exchange with lm2575
    [instrument_cluster.kicad_pcb]
2017-11-18 add commentary to scheme
    [power_supply.sch]
2017-11-18 working with pcb design
    [instrument_cluster.kicad_pcb]
2017-11-18 redone shematic of power supply, fix usb_vbus and swd diods connections, change mcu capacitors connections
    [2can_filter+extra.sch, 2can_filter.sch, instrument_cluster.kicad_pcb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]
2017-11-20 reduce board edge, finish module B tracing
    [instrument_cluster.kicad_pcb]
2017-11-22 switch to relative libs path
2017-11-22 add transient voltage suppression diods on CAN
    [2can_filter+extra.sch, 2can_filter.sch, instrument_cluster.kicad_pcb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]
2017-11-22 work on module A
    [instrument_cluster.kicad_pcb]
2017-11-23 add resistor on can STB pin module A
    [2can_filter.sch, instrument_cluster.kicad_pcb]
2017-11-23 TODO swd module A, anti-theft
    [instrument_cluster.kicad_pcb]
2017-11-24 pcb tracing finish
    [instrument_cluster.kicad_pcb]
2017-11-24 update graphics for readme file
    [instrument_cluster.FCStd, instrument_cluster.kicad_pcb, instrument_cluster1.stl]
2017-11-25 fix signal trace length usb module A
    [2can_filter.sch, instrument_cluster.kicad_pcb]
2017-12-02 fix files mods(permission)
    [2can_filter+extra.sch, 2can_filter.sch, instrument_cluster.FCStd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]
2017-12-05 sch&pcb: add LED`s and refresh readme image`s
    [2can_filter+extra.sch, 2can_filter.sch, instrument_cluster.kicad_pcb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]
2017-12-05 add usb 3d modele
    [2can_filter+extra.sch, 2can_filter.sch]
2017-12-06 add shell script to zip gerbers
2017-12-06 add gerbers files
    [instrument_cluster-B.Adhes.gbr, instrument_cluster-B.CrtYd.gbr, instrument_cluster-B.Cu.gbr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]
2017-12-06 zipped gerber files
2017-12-08 add descriptions for gerber files
2017-12-08 add BOM file
    [instrument_cluster_fp.xlsx]
2018-04-16 fix USB, swapped the traces D+ D-
    [2can_filter+extra.sch, 2can_filter.sch, instrument_cluster.kicad_pcb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]
2018-04-16 fix CAN, swapped the stm->to->can connection in module B
    [2can_filter+extra.sch, 2can_filter.sch, instrument_cluster.kicad_pcb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]
2018-04-17 fix USB footprint
    [2can_filter+extra.sch, 2can_filter.sch, instrument_cluster.kicad_pcb]
